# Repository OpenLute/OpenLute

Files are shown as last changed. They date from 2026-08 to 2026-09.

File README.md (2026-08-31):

# OpenLute

**Open-source, 3D-printable lute designs.**

OpenLute is an open-source hardware project focused on making playable, accessible lute designs that can be fabricated using modern digital manufacturing tools such as 3D printing.

The goal is to make it easier for builders, musicians, makers, and designers to **build, study, modify, improve, and share** lute designs.

## The Project

OpenLute is intended to be more than a single instrument. It is a framework for developing and sharing open lute designs across different historical styles, course counts, and approaches to construction.

The project begins with a Renaissance lute design:

### OL-R1

**OL-R1** is the first OpenLute Renaissance design.

The initial development target is a **7-course Renaissance lute**.

As the project develops, additional configurations, designs, and approaches may be added—including different course counts and other lute styles.

## What You'll Find Here

The OpenLute repository contains the project's source designs and supporting documentation, including:

* CAD source files
* Printable files
* Build and assembly documentation
* Hardware and materials information
* Recommended print settings
* Design documentation
* Development history
* Community contributions and modifications

The goal is for the repository to be the **official home for OpenLute designs and their development history.**

## Build It. Modify It. Improve It.

OpenLute is intended to be a community-driven project.

You are encouraged to build the instruments, experiment with them, identify problems, propose improvements, and develop your own variations.

Not every experiment will become part of an official OpenLute release. The project will maintain a distinction between **official OpenLute designs** and community-developed modifications or derivatives.

If you develop something useful, consider sharing it with the community so others can learn from it and build upon it.

## Current Status

OpenLute is an actively developing project.

| | |
|---|---|
| **Current design** | OL-R1 |
| **Configuration** | 7-course Renaissance lute |
| **Status** | Experimental |

The designs and documentation will continue to evolve as they are built and tested.

## Contributing

You don't need to be the original designer to contribute.

Useful contributions can include:

* Building and testing an instrument
* Reporting problems
* Suggesting design improvements
* Contributing CAD work
* Improving documentation
* Testing materials and print settings
* Developing accessories
* Sharing build experiences
* Developing alternative designs

Please see [CONTRIBUTING.md](CONTRIBUTING.md) for information about participating in the project.

## License

OpenLute hardware designs are released under the **CERN Open Hardware Licence Version 2 – Strongly Reciprocal (CERN-OHL-S-2.0)**.

In plain English, this means you are free to use, study, build, modify, and share the designs under the terms of the license. The license also permits commercial use.

If you distribute modified OpenLute designs, the license includes requirements intended to keep the corresponding design information available to others.

The complete license and its terms are provided in [LICENSE](LICENSE). The license is the authoritative source for your rights and obligations.

The **OpenLute name and branding are not granted as part of the hardware license**.

## Safety

OpenLute designs are physical objects that may contain components subjected to significant mechanical loads, including string tension.

The CERN-OHL-S-2.0 license provides the designs without warranties and limits liability to the extent permitted by applicable law. **Build and use OpenLute designs at your own risk.**

Please use appropriate safety practices when printing, assembling, stringing, tuning, modifying, and using an OpenLute instrument.

See [SAFETY.md](SAFETY.md) for basic safety guidance.

## Support OpenLute

OpenLute is supported through voluntary contributions. Information about supporting the project will be added as the project develops.

## Get Started

The current OpenLute design can be found here:

**[OL-R1 — 7-Course Renaissance Lute](instruments/renaissance/OL-R1/7-course/)**

Start there for the current design files and build documentation.

---

**OpenLute** is an evolving open-source project. Build one, learn from it, improve it, and share what you discover.

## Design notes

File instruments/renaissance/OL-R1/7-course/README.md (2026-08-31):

# OL-R1 — 7-Course Renaissance Lute

**OpenLute Renaissance Design 1 — 7-Course**

OL-R1 is the first Renaissance lute design developed as part of the OpenLute project.

This design is intended to provide a playable, reproducible lute that can be fabricated using commonly available 3D-printing equipment and materials.

## Status

**Experimental**

OL-R1 is an experimental design that is being actively built and tested. Dimensions, materials, construction methods, and other aspects of the design may change as testing and development continue.

Builders are encouraged to share their experiences, identify problems, and suggest improvements.

## About the Design

OL-R1 is designed around the construction of a Renaissance-style lute while taking advantage of modern digital fabrication.

The design files in this directory represent the current development of the 7-course configuration.

The design is intended to be:

* 3D printable
* Reproducible by other builders
* Open to modification and experimentation
* Documented sufficiently for others to build and evaluate

## Design Files

Design files for OL-R1 will be organized within this directory.

As the project develops, files may include:

* **CAD source** — editable source design files
* **Printable files** — STL or other manufacturing-ready files
* **Documentation** — build and assembly information
* **Print settings** — recommended manufacturing parameters
* **Hardware** — required hardware and components

See the individual directories for the current files and documentation.

## Building OL-R1

A complete build will require more than the printed components.

Builders should expect to use appropriate:

* Filament and other materials
* Strings
* Hardware
* Adhesives
* Tools
* 3D-printing equipment

Detailed requirements and build instructions will be documented as the design progresses.

## Development

OL-R1 is developed through a combination of CAD design, physical prototyping, testing, and community feedback.

If you build an OL-R1, feedback and build experience are valuable contributions to the project.

Please see the main repository's [CONTRIBUTING.md](../../../CONTRIBUTING.md) for information about contributing.

---

**OpenLute**
Open-source lute designs for builders, musicians, and makers.

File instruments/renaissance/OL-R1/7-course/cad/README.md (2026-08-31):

# CAD Source

This directory contains the editable Fusion 360 source files for OL-R1.

The primary source file is:

* `OL-R1-7-course.f3d`

## Current CAD Structure

The current design was developed as a single Fusion 360 timeline rather than as a fully component-based assembly.

The individual bodies are named to make the design easier to understand and work with, but the overall model has not yet been reorganized into separate components.

This reflects the current state of development and the way the design was originally created.

## Future Development

A future improvement would be to reorganize the design into a more conventional component-based Fusion 360 assembly.

This could make the design easier to:

* Modify individual parts
* Reuse components
* Develop alternate configurations
* Manage different instrument designs
* Contribute changes to specific parts of the design

**CAD restructuring is a potential contribution opportunity.** If you have experience with Fusion 360 assemblies and would like to help improve the organization of the OpenLute CAD source, contributions are welcome.

The existing parametric timeline should be preserved where practical during any restructuring.

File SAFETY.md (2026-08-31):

# Safety

OpenLute designs are open-source hardware provided under the **CERN Open Hardware Licence Version 2 – Strongly Reciprocal (CERN-OHL-S-2.0)**.

The license provides the designs without warranties and limits liability to the extent permitted by applicable law. **Build and use OpenLute designs at your own risk.**

When building or using an OpenLute, use appropriate safety practices for:

* 3D printing and fabrication equipment
* Hand and power tools
* Adhesives and other materials
* Hardware and structural components
* Strings and other tensioned components

Inspect components before use and do not use parts that are cracked, damaged, improperly manufactured, or otherwise appear unsafe.

When installing and tensioning strings, increase tension gradually and use appropriate caution. Stop if you observe cracking, deformation, unexpected movement, or other signs of failure.

Modifying a design, changing materials, changing print settings, or substituting hardware may affect the strength and behavior of the instrument.

**Use common sense, follow appropriate safety practices, and build responsibly.**

See [LICENSE](LICENSE) for the complete legal terms and disclaimers.

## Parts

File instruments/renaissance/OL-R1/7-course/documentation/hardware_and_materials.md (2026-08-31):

# OL-R1 — Hardware & Materials

This document lists hardware and materials currently used or recommended for the OL-R1 7-course Renaissance lute.

The OL-R1 design is experimental, and specific components may change as the design develops.

## Tuning Machines

The OL-R1 pegbox is currently designed around ukulele-style tuning machines.

**Current design reference:**

[Ukulele Tuning Machines — Amazon](https://www.amazon.com/dp/B0CKXYDDBK)

The pegbox geometry is designed around this style of tuner. If substituting different tuning machines, verify mounting dimensions and clearance before modifying or printing the pegbox.

## Strings

A 7-course lute string set is recommended.

### La Bella TL 7CRS #1

[La Bella TL 7CRS #1 — 7 Course Lute Strings](https://www.stringsbymail.com/la-bella-tl-7crs-1-lute-strings-7-course-full-set-4968.html)

This is the primary string set used/recommended for the current OL-R1 design.

### Alternate 7-Course Set

[7-Course Lute Strings — Amazon](https://www.amazon.com/dp/B004I4DT7U)

When using an alternative string set, select a set appropriate for a similar scale length and tuning. Different string materials and gauges can change the tension and response of the instrument.

## Pegbox Reinforcement Rod

The current OL-R1 design uses a **1/4-inch diameter steel rod** to reinforce the pegbox and neck.

### Rod Requirements

* Diameter: **1/4 inch**
* Pegbox section: **7 1/8 inches**
* Neck sections: **2 × 1 3/8 inches**

The 7 1/8-inch section is installed inside the pegbox reinforcement shaft and secured with epoxy.

The two 1 3/8-inch sections are used when joining the pegbox to the neck. These sections should be installed during the pegbox-to-neck assembly rather than during the initial pegbox reinforcement.

## Adhesive

Epoxy is currently used for the primary structural joints of the instrument, including:

* Bowl halves
* Soundboard halves
* Soundboard braces
* Soundboard-to-bowl connection
* Pegbox reinforcement rod
* Pegbox-to-neck reinforcement

### Recommended Epoxy

The current OL-R1 build uses **J-B Weld ClearWeld Quick-Setting Epoxy**.

[J-B Weld ClearWeld Quick-Setting Epoxy — Amazon](https://www.amazon.com/J-B-Weld-50240-ClearWeld-Quick-Setting/dp/B07TTTYKGS)

This is the epoxy used during development and testing of the current design.

A suitable alternative epoxy may be used, but builders should select an adhesive appropriate for the intended joint and follow the manufacturer's instructions for mixing, application, and curing.

## Optional Strap Handle

An optional strap handle can be installed at the end of the bowl.

The strap handle is not required for the basic OL-R1 build.

See the build guide for installation information.

---

## Notes

The components listed here represent the current OL-R1 build configuration. As the design is tested and refined, specific hardware and materials may be updated.

Where possible, future revisions will document both the component specification and suitable alternatives so builders are not dependent on a single supplier or product.

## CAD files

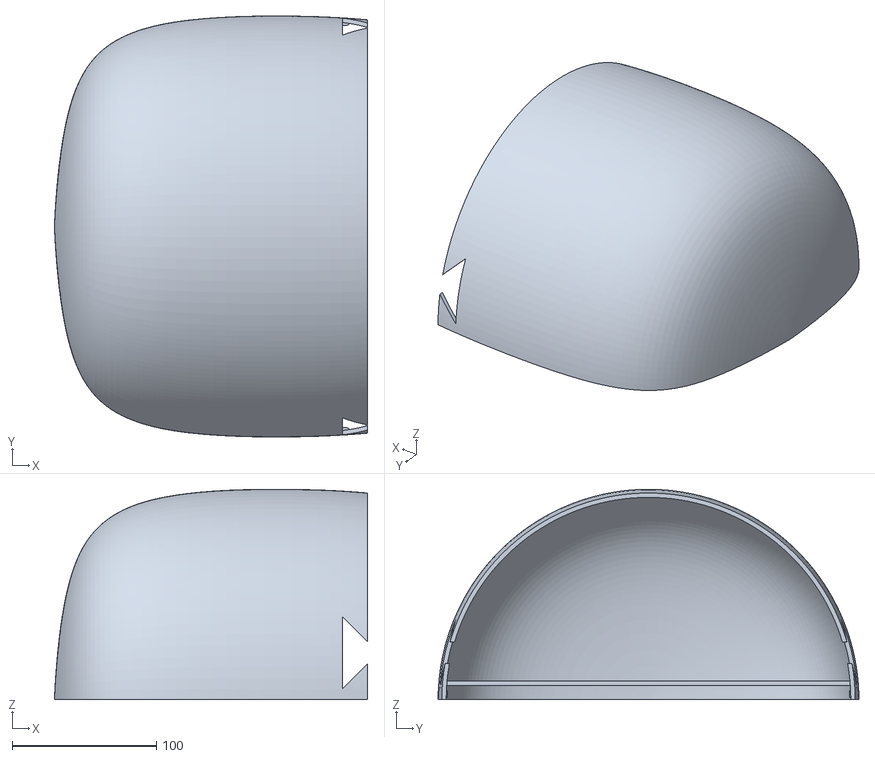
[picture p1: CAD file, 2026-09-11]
instruments/renaissance/OL-R1/7-course/printable/OL_R1_Bowl-Bot.stl
217.0 x 291.6 x 145.8

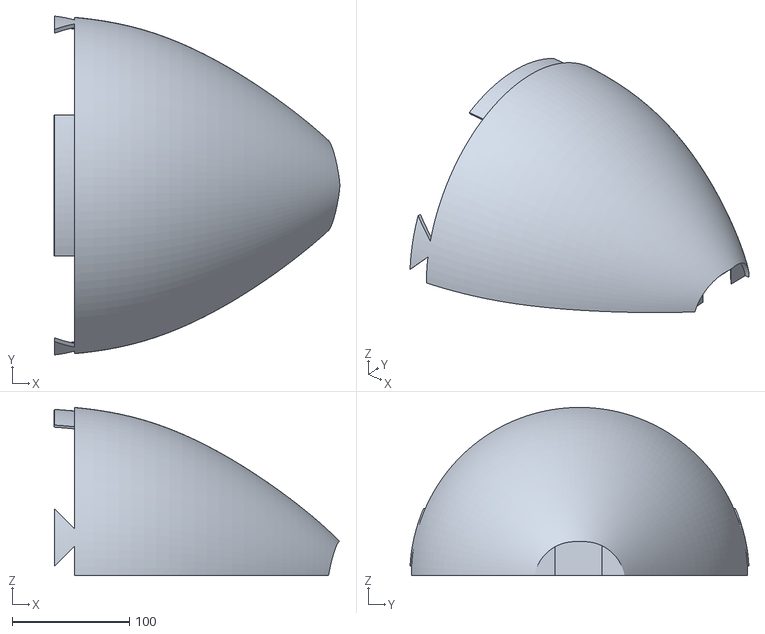
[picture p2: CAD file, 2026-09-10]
instruments/renaissance/OL-R1/7-course/printable/OL_R1_Bowl-Top.stl
243.2 x 288.5 x 143.2

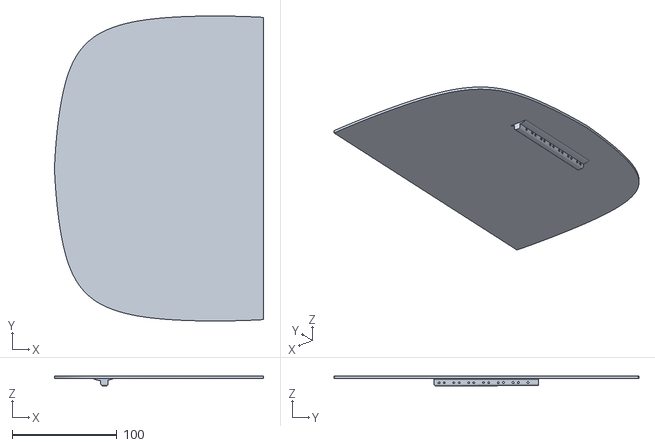
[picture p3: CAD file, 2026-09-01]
instruments/renaissance/OL-R1/7-course/printable/OL_R1_SndBrd-Bot.stl
200.0 x 291.6 x 9.49

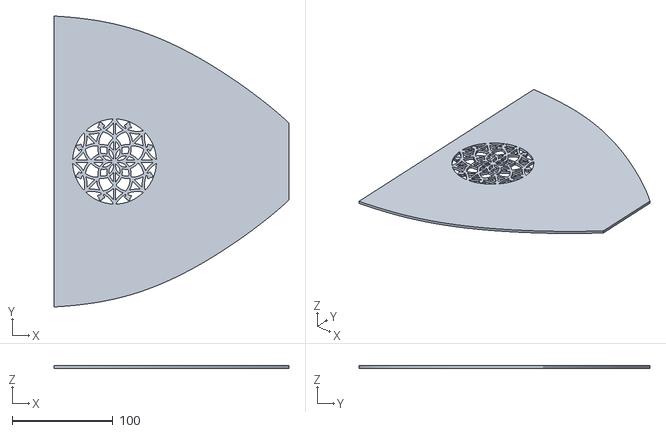
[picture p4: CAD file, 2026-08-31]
instruments/renaissance/OL-R1/7-course/printable/OL_R1_SndBrd-Top.stl
233.1 x 288.9 x 2.50

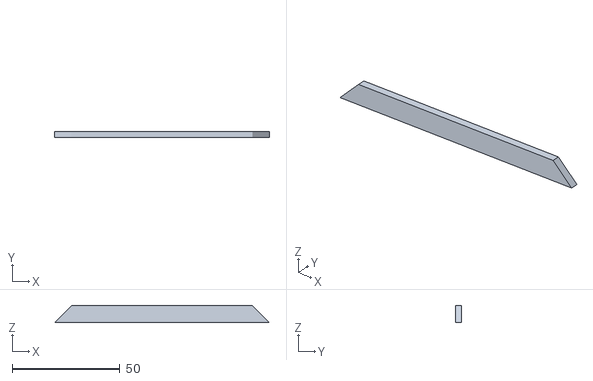
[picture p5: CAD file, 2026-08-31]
instruments/renaissance/OL-R1/7-course/printable/OL_R1_SndBrd-Bot-Brace3.stl
100.0 x 3.00 x 8.00

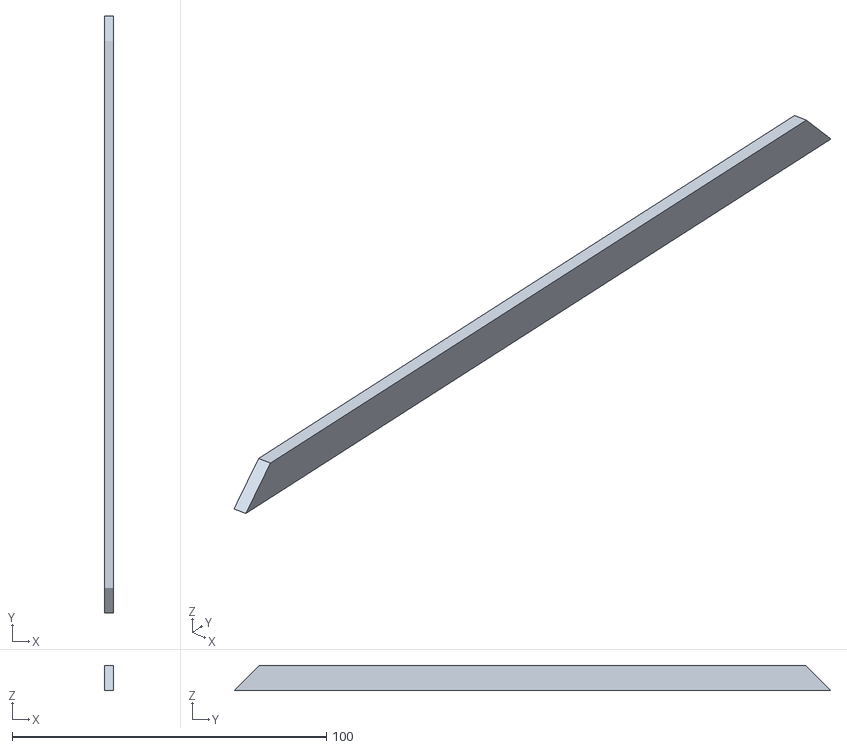
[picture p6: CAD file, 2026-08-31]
instruments/renaissance/OL-R1/7-course/printable/OL_R1_SndBrd-Top-Brace1.stl
3.00 x 190.0 x 8.00

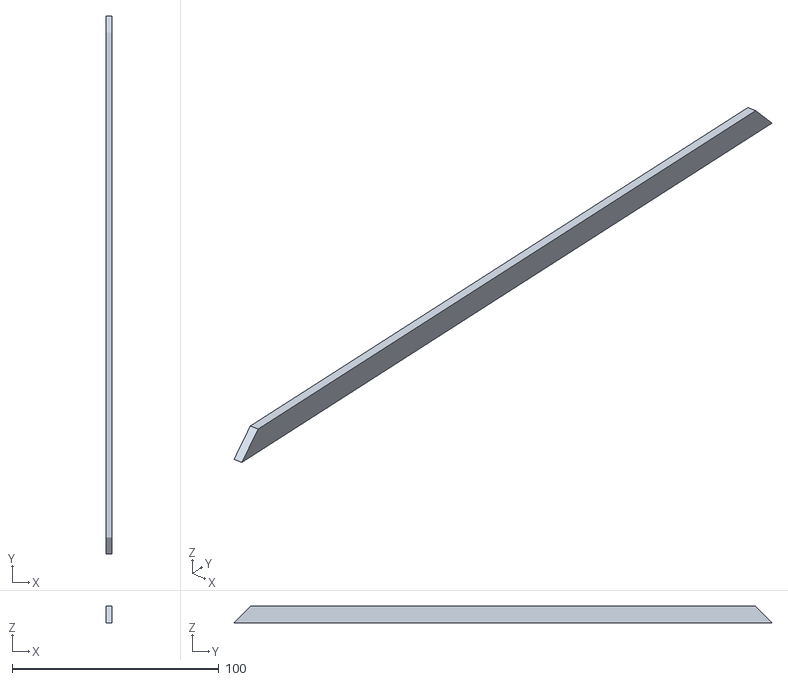
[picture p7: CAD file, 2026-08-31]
instruments/renaissance/OL-R1/7-course/printable/OL_R1_SndBrd-Bot-Brace1.stl
3.00 x 260.0 x 8.00

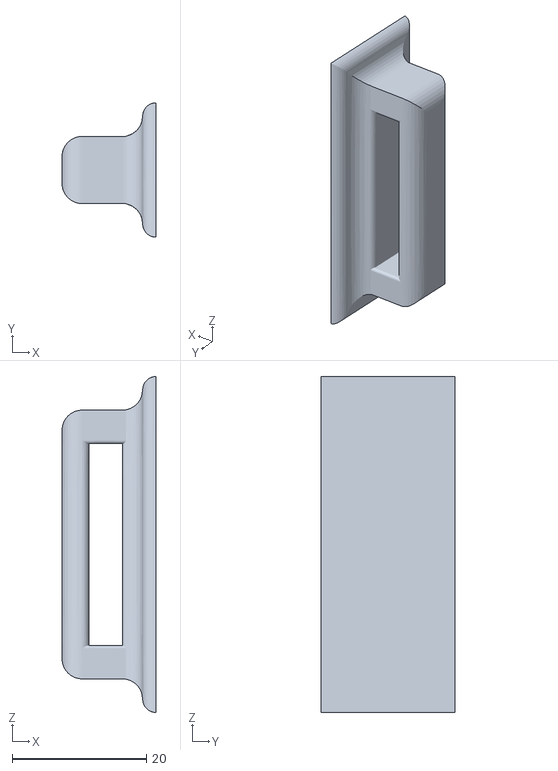
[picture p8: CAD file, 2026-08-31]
instruments/renaissance/OL-R1/7-course/printable/OL_R1_Strap Handle.stl
14.0 x 20.0 x 50.0

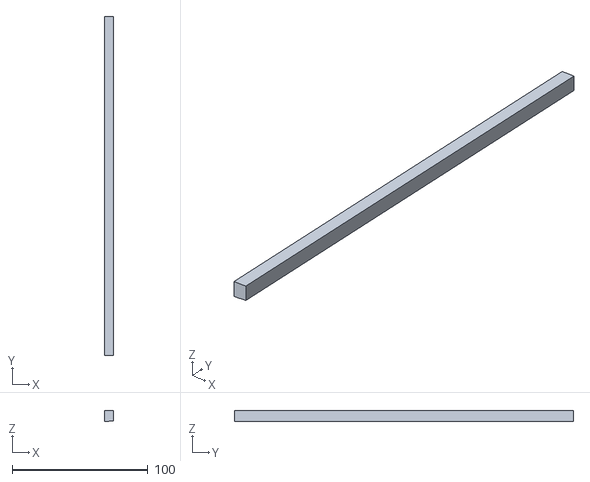
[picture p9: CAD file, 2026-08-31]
instruments/renaissance/OL-R1/7-course/printable/OL_R1_SndBrd-Connector.stl
7.00 x 250.0 x 8.00

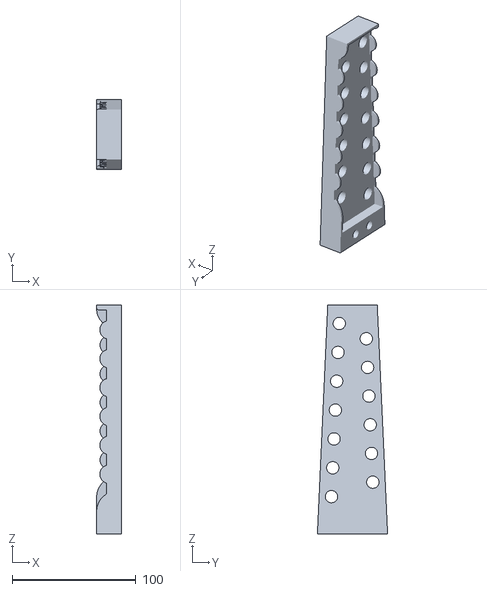
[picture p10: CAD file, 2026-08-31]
instruments/renaissance/OL-R1/7-course/printable/OL_R1_Pegbox.stl
20.0 x 56.7 x 185.0

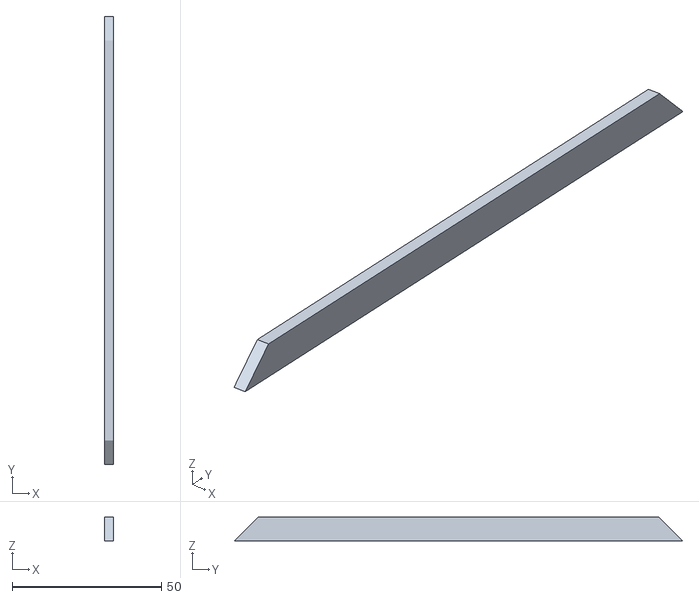
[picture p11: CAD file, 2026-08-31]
instruments/renaissance/OL-R1/7-course/printable/OL_R1_SndBrd-Top-Brace2.stl
3.00 x 150.0 x 8.00

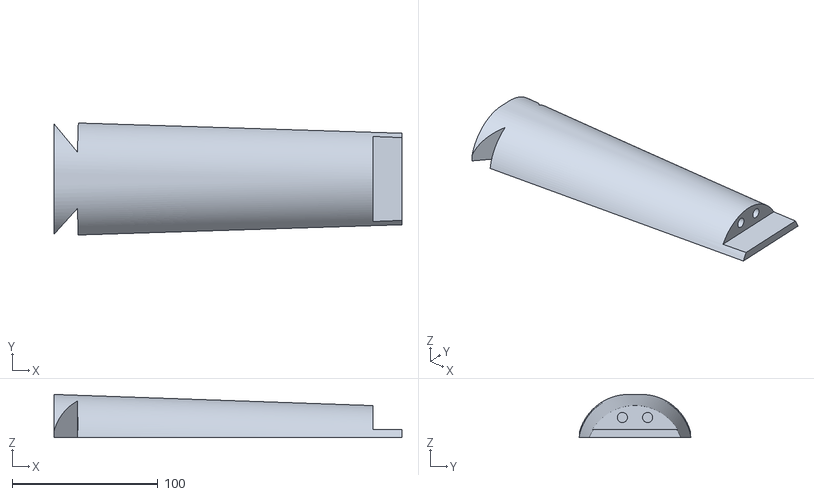
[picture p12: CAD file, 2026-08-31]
instruments/renaissance/OL-R1/7-course/printable/OL_R1_Neck.stl
238.6 x 76.8 x 29.6

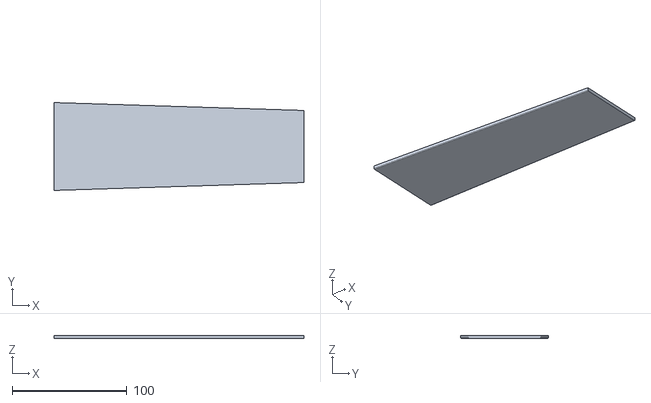
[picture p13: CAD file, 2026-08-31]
instruments/renaissance/OL-R1/7-course/printable/OL_R1_Fret-Board.stl
217.7 x 76.5 x 2.90

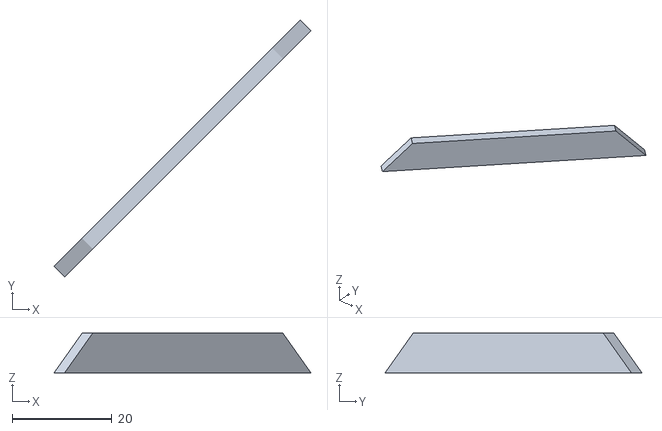
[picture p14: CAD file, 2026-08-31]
instruments/renaissance/OL-R1/7-course/printable/OL_R1_SndBrd-Bot-Brace4.stl
51.6 x 51.6 x 8.00

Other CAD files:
instruments/renaissance/OL-R1/7-course/printable/OL_R1_SndBrd-Bot-Brace2.stl
instruments/renaissance/OL-R1/7-course/printable/OL_R1_Nut.stl
instruments/renaissance/OL-R1/7-course/cad/OL-R1-7-course.f3d

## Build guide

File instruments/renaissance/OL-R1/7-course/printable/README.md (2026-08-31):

# Printable Files

This directory contains the current printable STL files for the OL-R1 7-course Renaissance lute.

These files are generated from the CAD source and are intended for use with a 3D printer.

For the editable design source, see the [`cad`](../cad/) directory.

For recommended printing parameters, see the [`print-settings`](../print-settings/) directory.

For assembly instructions and required hardware, see the [`documentation`](../documentation/) directory.

## File Naming

STL files use the following naming convention:

`OL-R1-<Part>.stl`

For example:

`OL-R1-Bowl-Top.stl`

The course configuration is established by the directory containing the files, so it is not repeated in each filename.

## Tested Printing Environment

The current OL-R1 printable files have been developed and tested using a **Qidi Plus4** 3D printer with **Qidi Studio** slicing software.

Other printers and slicers may require adjustments to print settings. See the [`print-settings`](../print-settings/) directory for additional information.

## Current Status

The OL-R1 design is **experimental**. Printable files may change as the design is tested and refined.

When using an STL, check the repository history and current release information to ensure you are using the intended version.

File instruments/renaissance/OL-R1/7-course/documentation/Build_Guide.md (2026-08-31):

# OL-R1 — 7-Course Renaissance Lute

## Build Guide

This guide describes the current assembly process for the OL-R1 7-course Renaissance lute.

The design is experimental and may change as additional builds are completed and tested.

---

## 1. Bowl Assembly

### Parts

* Bowl top half × 1
* Bowl bottom half × 1

### Assembly

1. Print the bowl top half and bottom half.
2. Take care when removing supports. The dovetail features are somewhat fragile and may require additional strengthening in future revisions.
3. Test-fit the two halves and make sure the dovetails are properly aligned.
4. Apply epoxy to the mating edges of the bowl halves.
5. Assemble the two halves and place the bowl with the open side facing down while the epoxy cures. This helps maintain alignment and produces a tight seal along the joint.
6. Once the initial epoxy has cured, turn the bowl over.
7. Fill any remaining gaps with epoxy.
8. Apply additional epoxy along the inside of the joint to reinforce the connection.

Allow the epoxy to fully cure according to the manufacturer's instructions before proceeding.

---

## 2. Soundboard Assembly

### Parts

* Soundboard top half × 1
* Soundboard bottom half × 1
* SndBrd-Connector × 1
* SndBrd-Top Brace1 × 1
* SndBrd-Top Brace2 × 1
* SndBrd-Bot-Brace1 × 1
* SndBrd-Bot-Brace2 × 1
* SndBrd-Bot-Brace3 × 5

### Assembly

1. Print the soundboard top half and bottom half.
2. Epoxy the two soundboard halves together.
3. Print the soundboard support pieces listed above.
4. Glue the support pieces to the underside of the soundboard according to the image below.

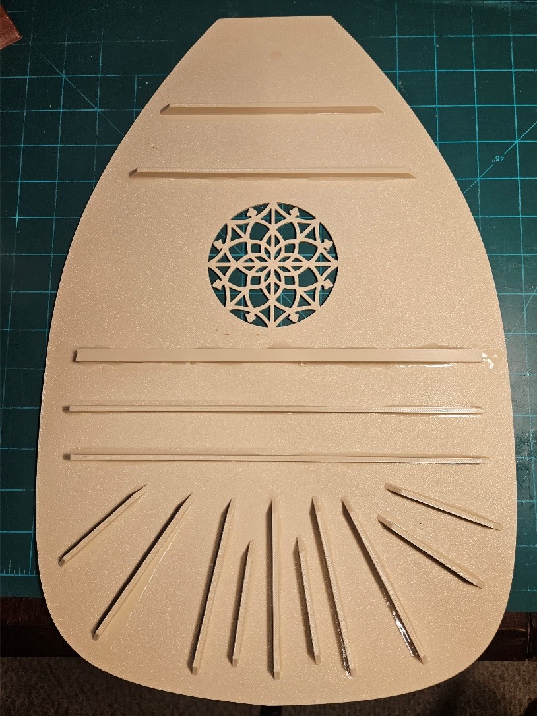
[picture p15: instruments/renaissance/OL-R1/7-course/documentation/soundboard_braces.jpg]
Soundboard brace locations


5. Allow the adhesive to fully cure before attaching the soundboard to the bowl.

---

## 3. Neck Assembly

### Parts

* Neck
* Bowl assembly

### Assembly

1. Glue the neck to the completed bowl assembly.
2. Carefully align the neck with the centerline of the instrument.
3. Flip the assembly over and place it on a flat surface while the adhesive cures. This helps keep the assembly flat and properly aligned.
4. Allow the adhesive to fully cure before continuing.

---

## 4. Fingerboard

### Parts

* Fingerboard
* Neck assembly

### Assembly

1. Once the neck is attached to the bowl, position the fingerboard on the neck.
2. Check the alignment of the fingerboard with the centerline of the neck.
3. Glue the fingerboard to the neck.
4. Allow the adhesive to fully cure before continuing.

---

## 5. Nut

### Parts

* Nut
* Fingerboard / neck assembly

### Assembly

1. Position the nut at the end of the fingerboard.
2. Check that the nut is properly aligned with the centerline of the fingerboard and neck.
3. Glue the nut in place.
4. Allow the adhesive to fully cure before installing and tensioning the strings.

---

## 6. Pegbox Reinforcement

The pegbox is reinforced using a 1/4-inch diameter rod.

### Parts

* 1/4-inch diameter reinforcement rod
* Epoxy

### Reinforcement Rods

Cut the following sections from the 1/4-inch rod:

* **1 × 7 1/8-inch section** — pegbox reinforcement shaft
* **2 × 1 3/8-inch sections** — neck reinforcement sections

### Pegbox Reinforcement

1. Cut one 7 1/8-inch section of 1/4-inch diameter rod.
2. Insert the rod into the reinforcement shaft in the pegbox.
3. Secure the rod in place with epoxy.
4. Allow the epoxy to cure.

### Neck Reinforcement

The two 1 3/8-inch sections are installed when the pegbox is joined to the neck.

1. Do not install these sections during the initial pegbox reinforcement step.
2. When joining the pegbox to the neck, apply epoxy to the appropriate ends of the reinforcement rods.
3. Join the pegbox and neck while ensuring the reinforcement rods are properly aligned.
4. Allow the epoxy to fully cure before applying load to the assembly.

---

## 7. Soundboard to Bowl Assembly

Once the soundboard assembly is complete:

1. Test-fit the soundboard assembly to the bowl.

2. Verify that the soundboard is correctly aligned with the bowl and neck.

3. Apply adhesive around the mating surface.

4. Position the soundboard on the bowl.

5. The soundboard extends slightly beyond the bowl at the bridge end.

   This appears to be related to dimensional differences or shrinkage in the printed bowl. The slight overhang is intentional in the current build and provides an area where additional epoxy can be applied to reinforce the connection between the soundboard and bowl.

6. Apply additional epoxy in the overhang area to reinforce the bond between the soundboard and bowl.

7. Secure the assembly in position while the adhesive cures.

8. Allow the adhesive to fully cure before proceeding.

---

## 8. Optional Strap Handle

A strap handle can optionally be added to the end of the bowl.

The strap handle is **not required** for the basic construction of the OL-R1 and can be added according to the builder's preference.

### Parts

* Strap handle
* Appropriate mounting hardware and/or adhesive

### Installation

1. Position the strap handle at the end of the bowl.
2. Verify the desired location and alignment before attaching it.
3. Secure the strap handle using the intended mounting method.
4. Allow any adhesive to fully cure before attaching a strap or applying load.

---

## Assembly Notes

This build guide documents the current experimental assembly process for OL-R1.

As additional instruments are built, these instructions may be updated to reflect improved assembly methods, revised components, or lessons learned from testing.

When building an OL-R1, refer to the current design files and documentation rather than relying on instructions from older versions of the design.

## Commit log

2026-08-31 Cad and printables
    * Create README.md
    * Add files via upload
    * Rename OL-R1-7-course.f3d.f3d to OL-R1-7-course.f3d
    * Create README.md
    * Add files via upload
    [OL-R1-7-course.f3d, OL_R1_Bowl-Bot.stl, OL_R1_Bowl-Top.stl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]
2026-09-01 raising_bridge-holes (#6)
    [OL-R1-7-course.f3d, OL_R1_SndBrd-Bot.stl]
2026-09-10 On branch dovetail_strengthen (#9)
    [OL-R1-7-course.f3d, OL_R1_Bowl-Top.stl]
2026-09-11 On branch dovetail_bot_strengthen (#10)
    [OL-R1-7-course.f3d, OL_R1_Bowl-Bot.stl]
